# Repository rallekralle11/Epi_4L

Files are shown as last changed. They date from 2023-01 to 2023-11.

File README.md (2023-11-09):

# Epi
# This thing is about to get launched on Crowd Supply

Named after the Epipactis genus of orchids. The flower of one appears on the board.

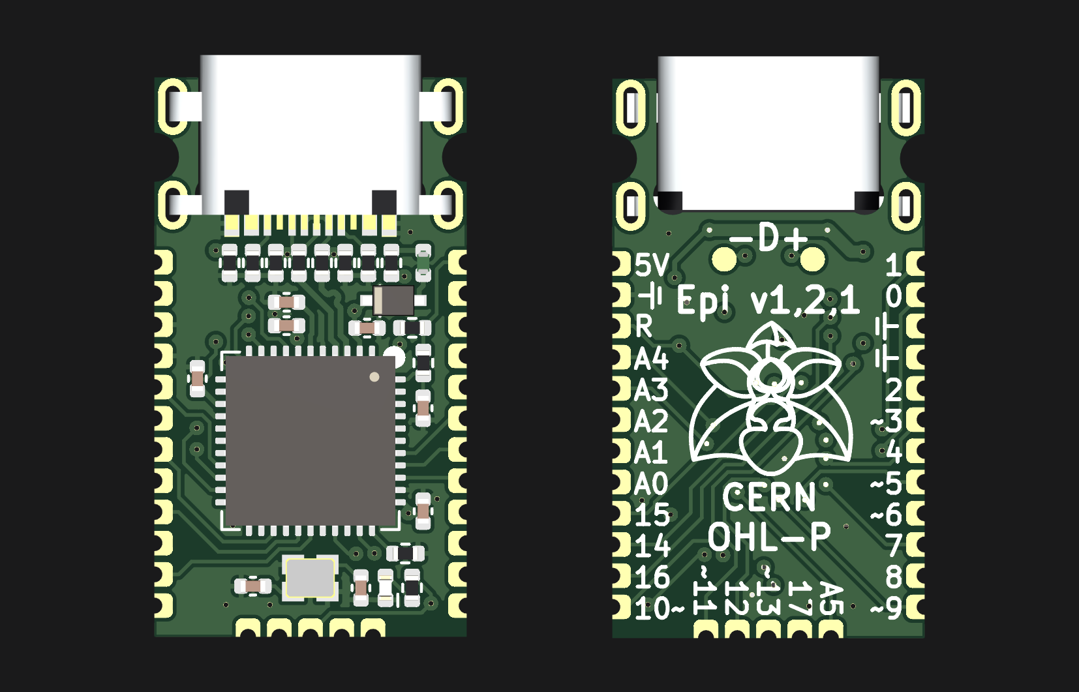
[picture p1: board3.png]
board


Data sheet: https://ping-el.se/wp-content/uploads/2023/10/datasheet.pdf
Kicad footprints: https://github.com/rallekralle11/kicad-lib

With such "amazing" features as:

USB power and data line ESD protection as well as power filtration and a fuse.

Crenellated pins.

No integrated voltage converter, only runs at 4,5-5,5v(down to 2,7 if you make it with an 8mhz crystal, or use the internal oscillator).

USB-C connector sunk into the board, and slighly portruding from the end for panel mounting.

1,27mm pin spacing.

Extra pins broken out.

Holes where M2 bolts can be used to hold it in place.

No rx/tx/power LEDs. Only one on pin 13 for testing.

Includes some custom footprints with 3D models.

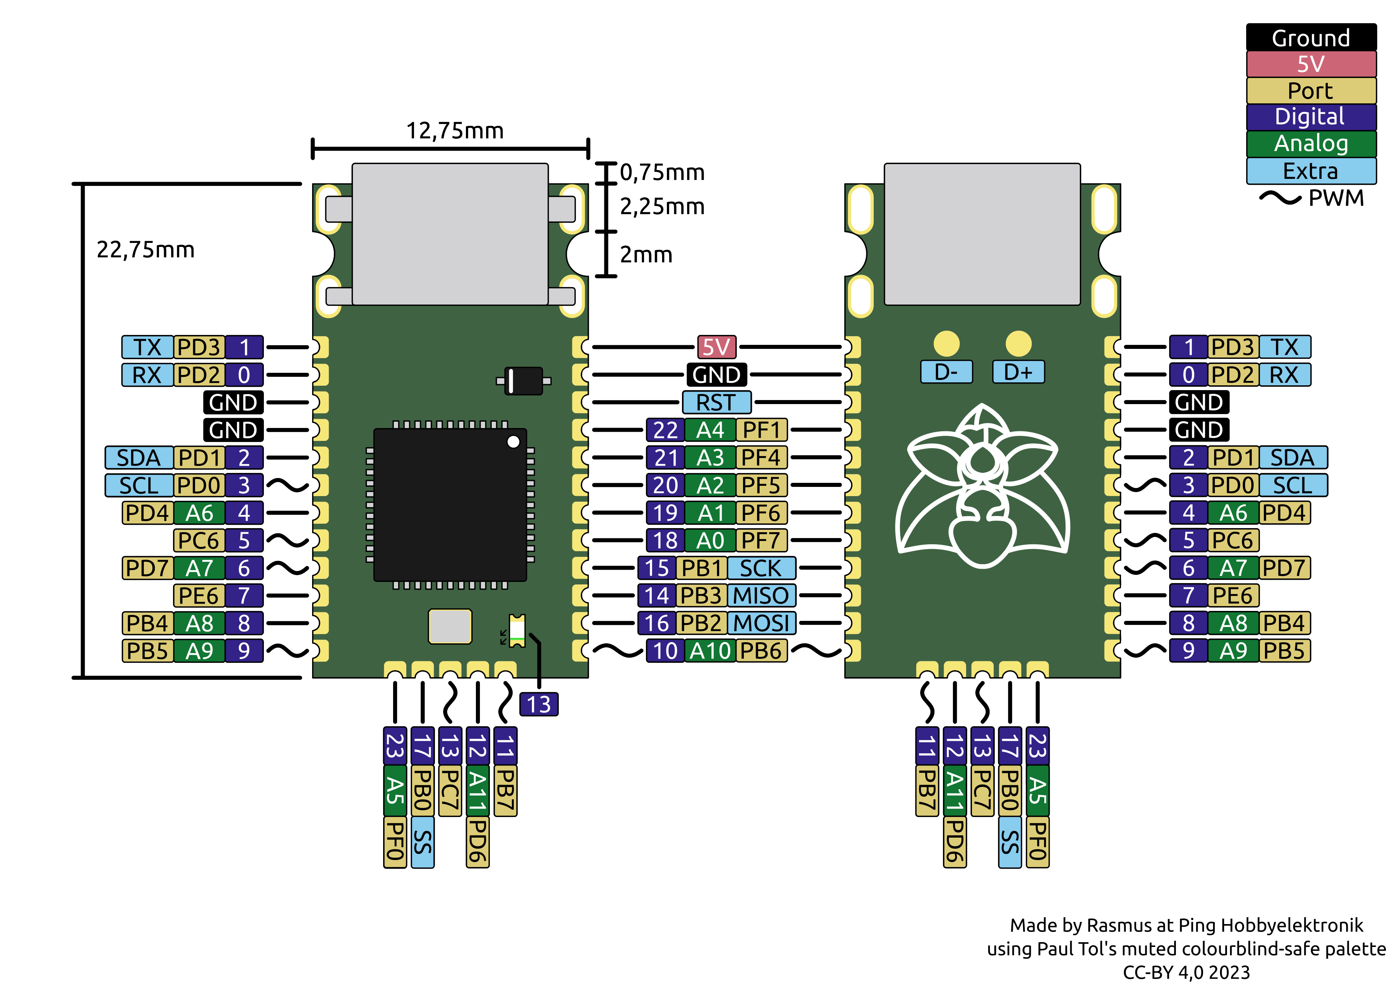
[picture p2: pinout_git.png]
pinout


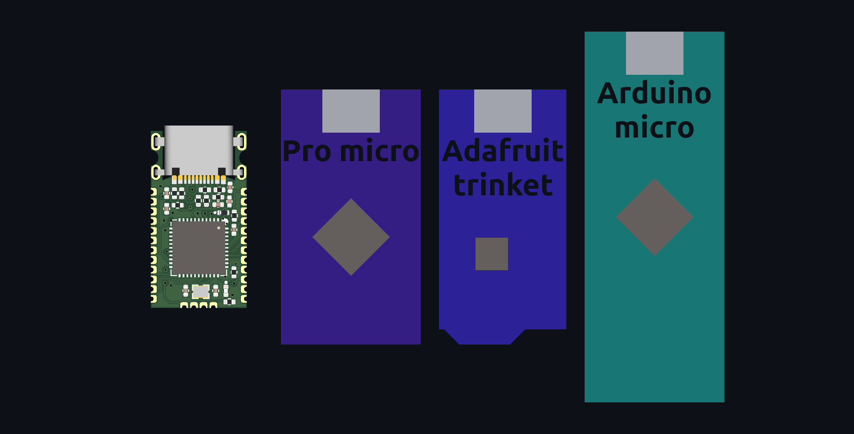
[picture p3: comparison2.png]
comp

Size comparisons.

Licensed under CERN-OHL-P v2

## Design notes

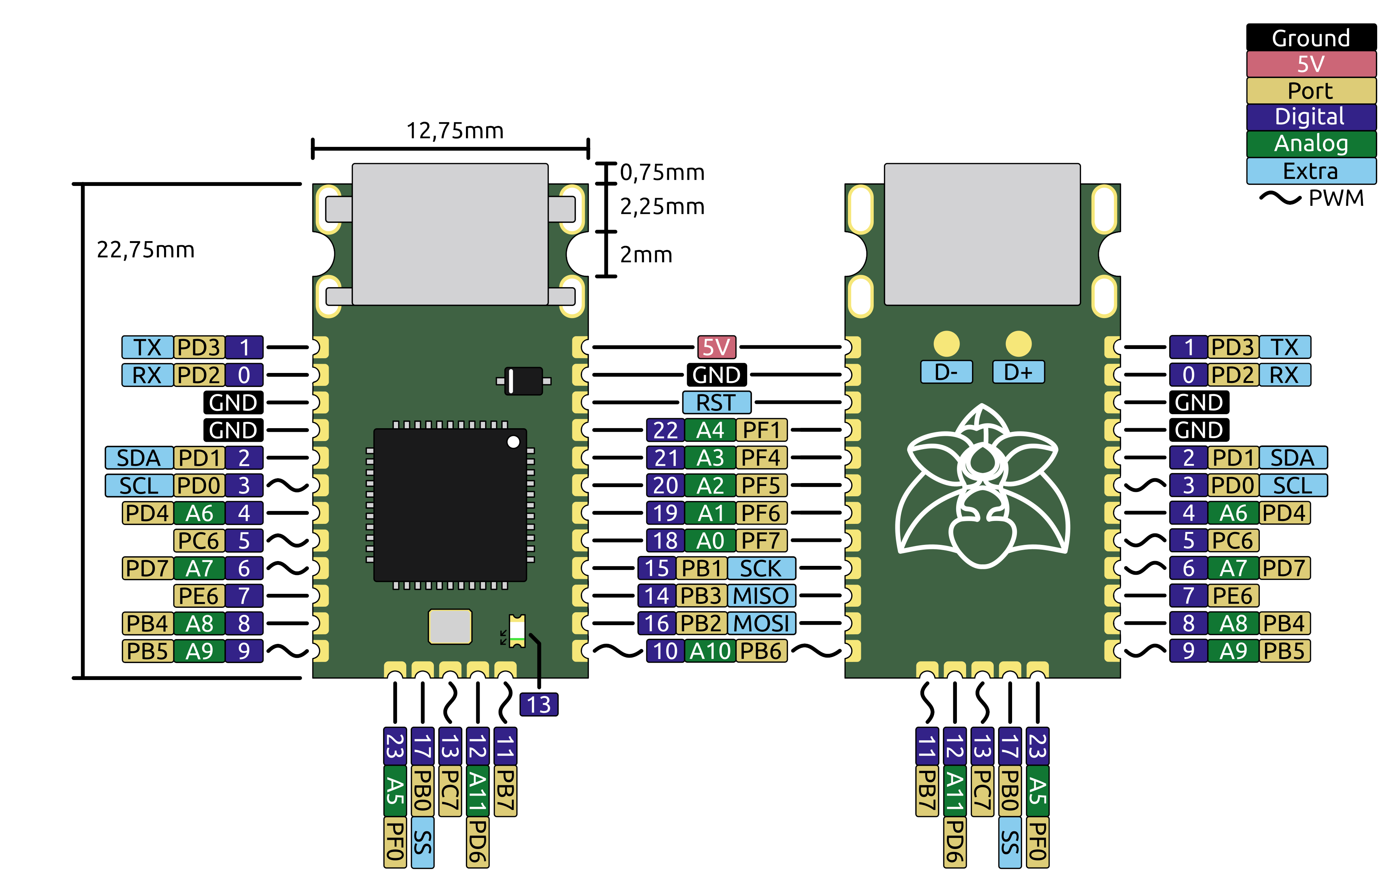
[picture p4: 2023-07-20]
epi-32u4-pinout-vit-crop.png

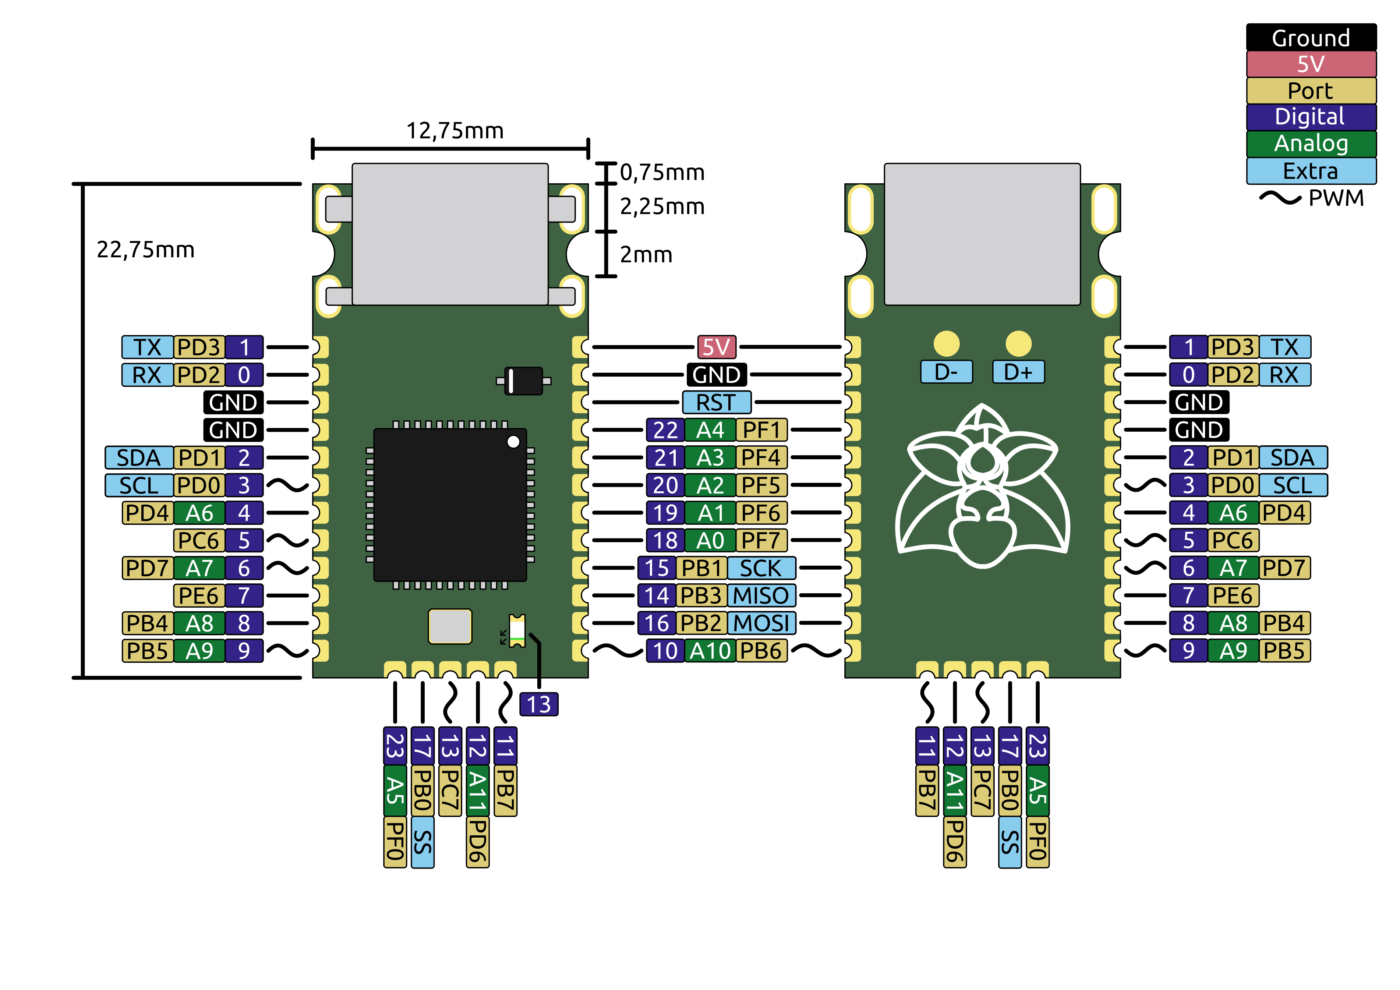
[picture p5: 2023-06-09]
epi-32u4-pinout-trans.png

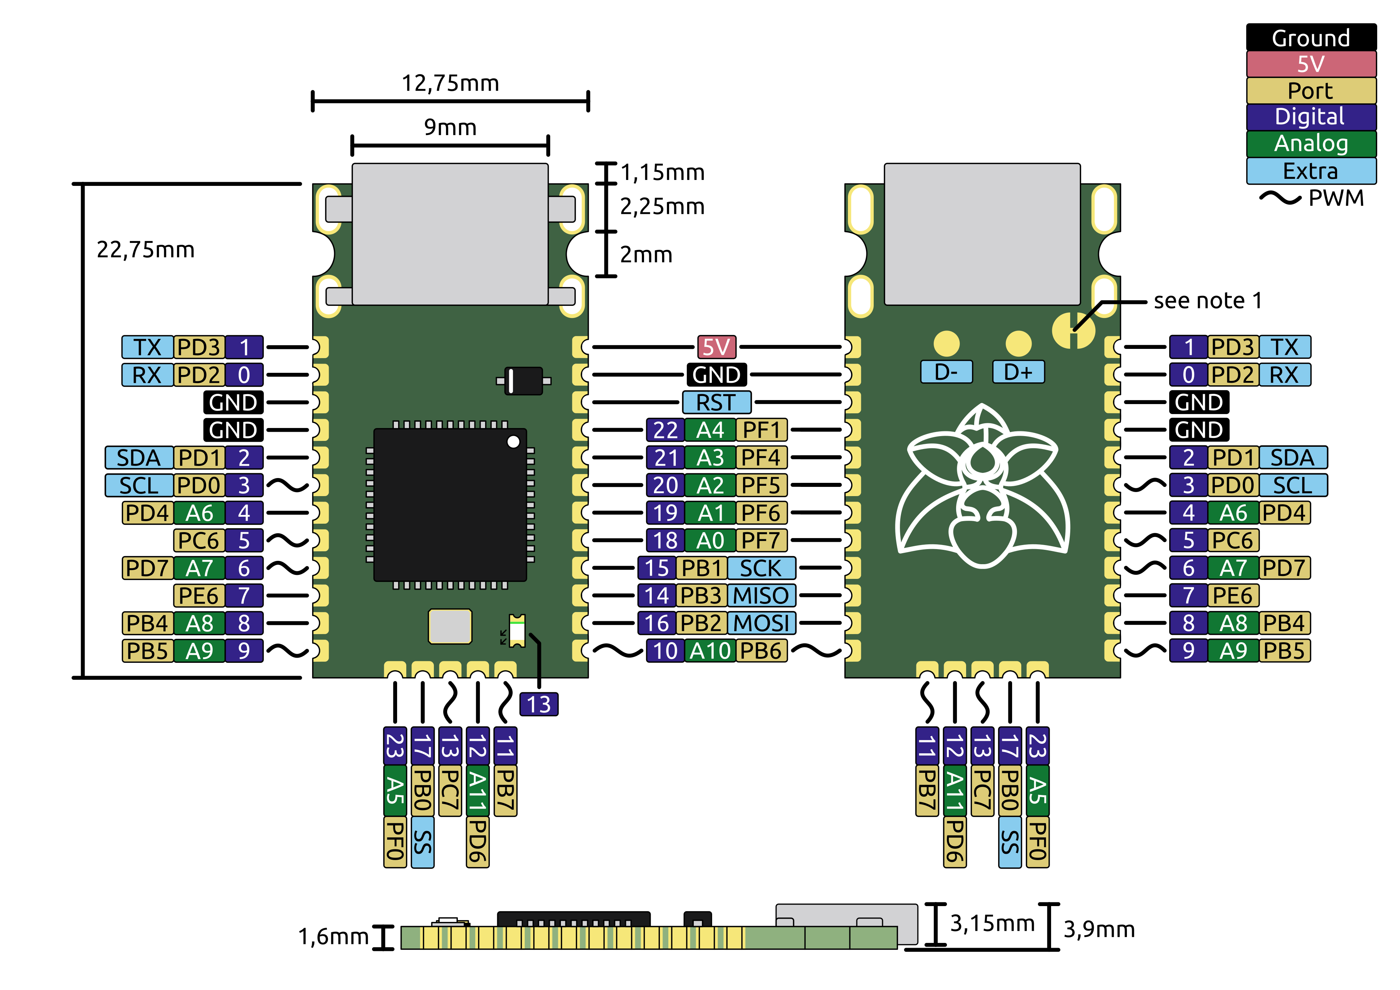
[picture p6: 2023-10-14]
pinout_trans.png

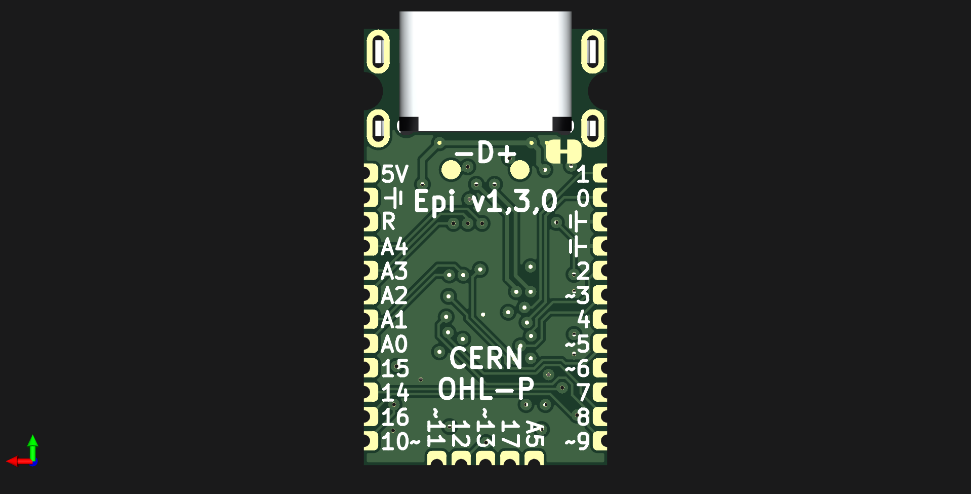
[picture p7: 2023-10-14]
B.png

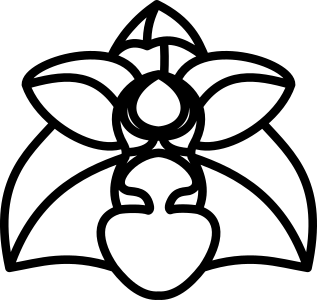
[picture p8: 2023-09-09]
extra/path1472-0-3-0-6.png

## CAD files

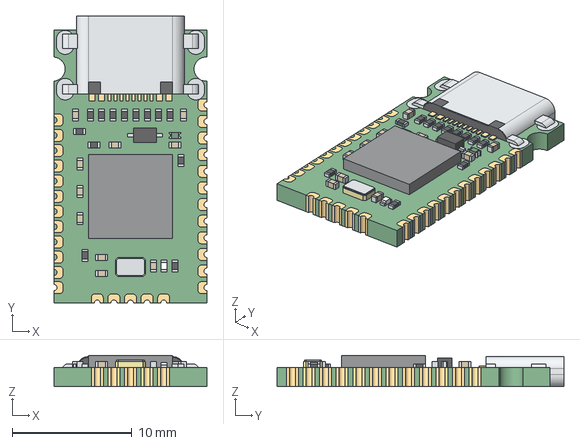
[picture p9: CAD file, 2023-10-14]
extra/Epi_footprint.stp
12.8 x 23.9 x 2.60 mm

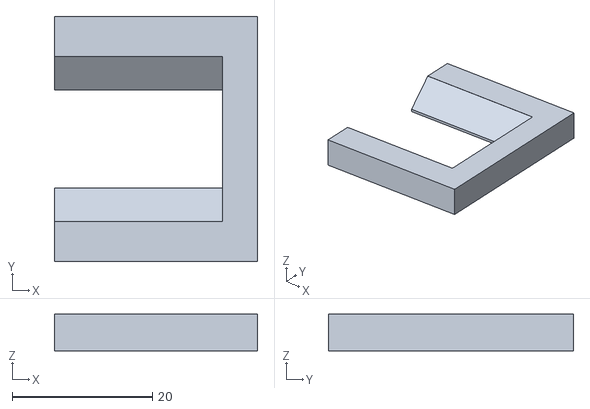
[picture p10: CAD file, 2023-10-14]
extra/jig.stl
29.0 x 35.0 x 5.25

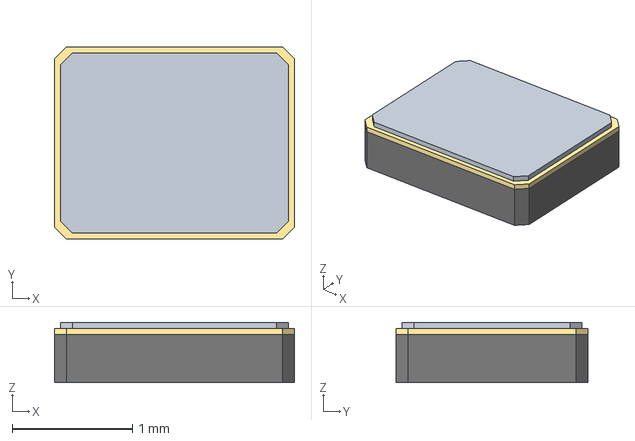
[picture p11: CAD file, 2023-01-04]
extra/crystal.stp
2.00 x 1.60 x 0.5 mm

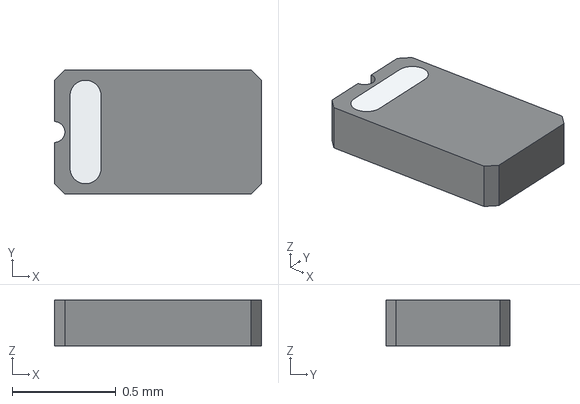
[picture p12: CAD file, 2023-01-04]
extra/diode.stp
1.00 x 0.6 x 0.22 mm

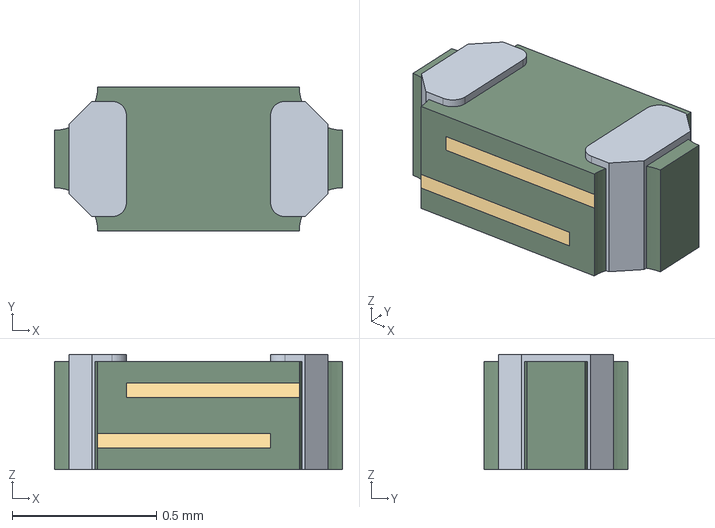
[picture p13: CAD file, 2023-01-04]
extra/1005_polyfuse.stp
1.00 x 0.5 x 0.4 mm

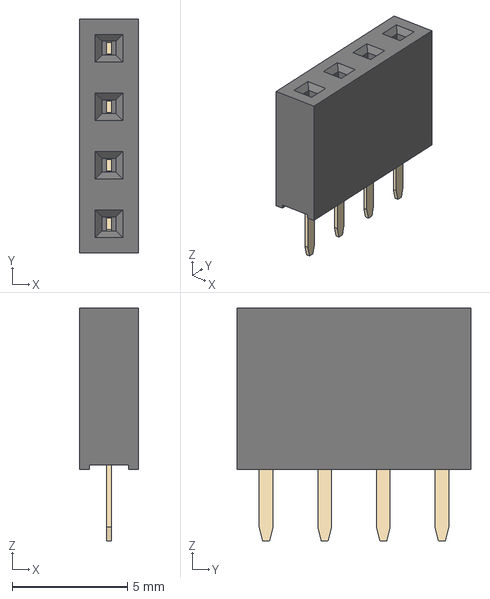
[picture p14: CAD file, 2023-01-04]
extra/PinSocket_1x04_P2.54mm_Vertical.step
2.54 x 10.2 x 10.1 mm

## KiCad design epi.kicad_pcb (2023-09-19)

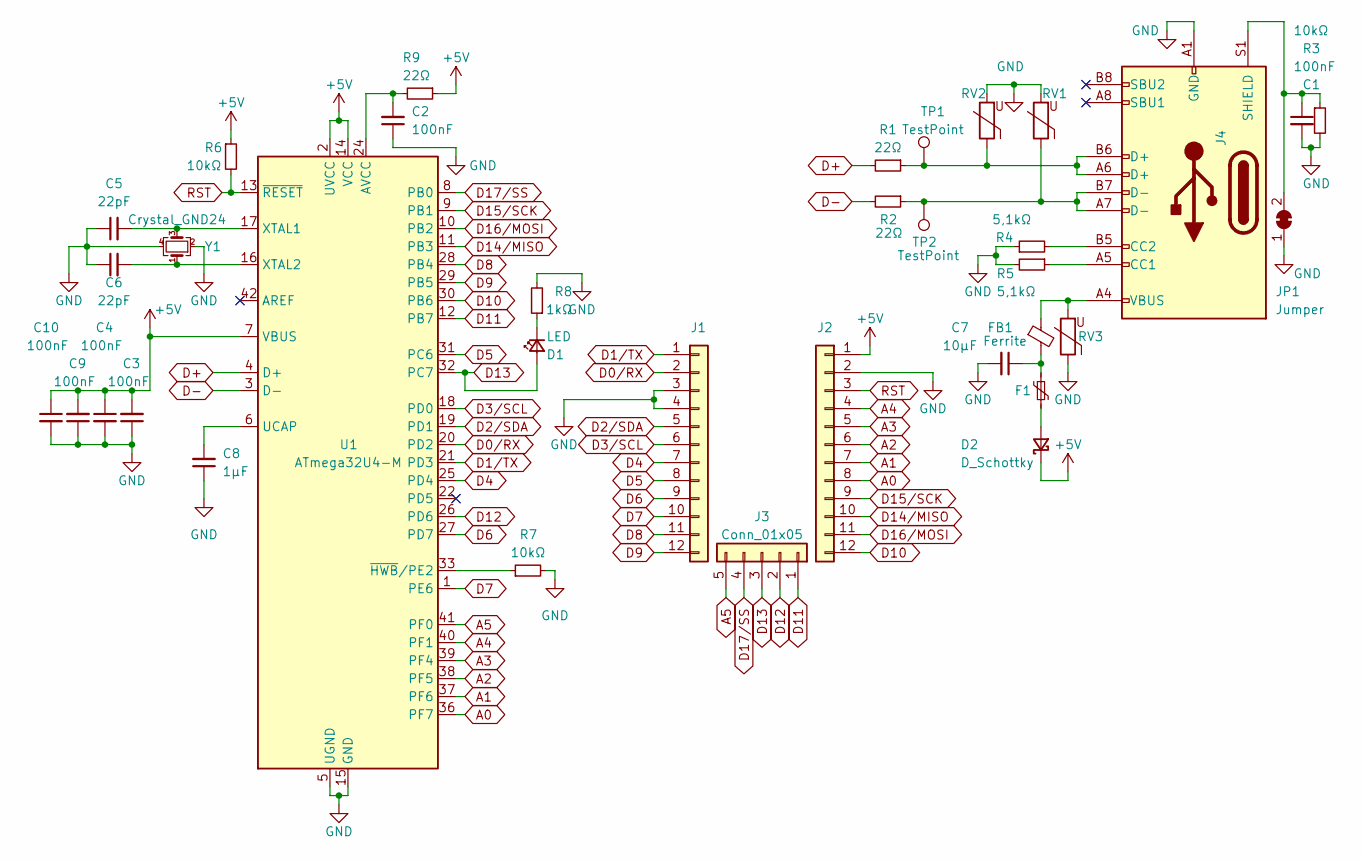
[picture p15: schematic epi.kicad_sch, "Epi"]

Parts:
C1, C2, C3, C4, C9, C10: 100nF; R_0402_1005Metric
C5, C6: 22pF; R_0402_1005Metric
C7: 10µF; R_0402_1005Metric
C8: 1µF; R_0402_1005Metric
D1: LED; LED_0402_1005Metric
D2: D_Schottky; SOD323_bättre
F1: Polyfuse 500mA HC; R_0402_1005Metric
FB1: Ferrite; R_0402_1005Metric
J1, J2: Connector 1x12; PinHeader_1x12_P1.27mm_Vertical
J3: Conn_01x05; PinHeader_1x05_P1.27mm_Vertical
J4: USB-C 2.0 mid-mount female connector; USB-C MC-314C-4P16
JP1: Jumper; SolderJumper-2_P1.3mm_Bridged_RoundedPad1.0x1.5mm
R1, R2, R9: 22Ω; R_0402_1005Metric
R3, R6, R7: 10kΩ; R_0402_1005Metric
R4, R5: 5,1kΩ; R_0402_1005Metric
R8: 1kΩ; R_0402_1005Metric
RV1, RV2, RV3: ESD protection varistor; R_0402_1005Metric
TP1, TP2: TestPoint; TestPoint_Pad_D1.0mm
U1: ATmega32U4-M; QFN-44-1EP_7x7mm_P0.5mm_EP5.2x5.2mm
Y1: Crystal_GND24; Crystal_SMD_2016-4Pin_2.0x1.6mm

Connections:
+5V: C3.2, C4.1, C9.2, C10.1, D2.1 (K), J2.1, R6.1, R9.1, U1.2 (UVCC), U1.7 (VBUS), U1.14 (VCC), U1.34 (VCC)
A0: J2.8, U1.36 (PF7)
A1: J2.7, U1.37 (PF6)
A2: J2.6, U1.38 (PF5)
A3: J2.5, U1.39 (PF4)
A4: J2.4, U1.40 (PF1)
A5: J3.5, U1.41 (PF0)
D0/RX: J1.2, U1.20 (PD2)
D1/TX: J1.1, U1.21 (PD3)
D2/SDA: J1.5, U1.19 (PD1)
D3/SCL: J1.6, U1.18 (PD0)
D4: J1.7, U1.25 (PD4)
D5: J1.8, U1.31 (PC6)
D6: J1.9, U1.27 (PD7)
D7: J1.10, U1.1 (PE6)
D8: J1.11, U1.28 (PB4)
D9: J1.12, U1.29 (PB5)
D10: J2.12, U1.30 (PB6)
D11: J3.1, U1.12 (PB7)
D12: J3.2, U1.26 (PD6)
D13: D1.2 (A), J3.3, U1.32 (PC7)
D14/MISO: J2.10, U1.11 (PB3)
D15/SCK: J2.9, U1.9 (PB1)
D16/MOSI: J2.11, U1.10 (PB2)
D17/SS: J3.4, U1.8 (PB0)
D+: R1.2, U1.4 (D+)
D-: R2.2, U1.3 (D-)
GND: C1.2, C2.1, C3.1, C4.2, C5.1, C6.1, C7.2, C8.1, C9.1, C10.2, J1.3, J1.4, J2.2, J4.A1 (GND), J4.A12 (GND), J4.B1 (GND), J4.B12 (GND), JP1.1 (A), R3.2, R4.1, R5.2, R7.2, R8.2, RV1.2, RV2.2, RV3.1, U1.5 (UGND), U1.15 (GND), U1.23 (GND), U1.35 (GND), U1.43 (GND), U1.45 (GND), Y1.2, Y1.4
unnamed: C2.2, R9.2, U1.24 (AVCC), U1.44 (AVCC)
unnamed: C7.1, F1.1, FB1.2
unnamed: D1.1 (K), R8.1
unnamed: D2.2 (A), F1.2
unnamed: FB1.1, J4.A4 (VBUS), J4.A9 (VBUS), J4.B4 (VBUS), J4.B9 (VBUS), RV3.2
unnamed: J4.A5 (CC1), R5.1
unnamed: J4.B5 (CC2), R4.2
unnamed: J4.A6 (D+), J4.B6 (D+), R1.1, RV2.1, TP1.1
unnamed: J4.A7 (D-), J4.B7 (D-), R2.1, RV1.1, TP2.1
unnamed: C1.1, J4.S1 (SHIELD), JP1.2 (B), R3.1
unnamed: C8.2, U1.6 (UCAP)
unnamed: C5.2, U1.17 (XTAL1), Y1.3
unnamed: C6.2, U1.16 (XTAL2), Y1.1
unnamed: R7.1, U1.33 (~HWB/PE2)
RST: J2.3, R6.2, U1.13 (~RESET)

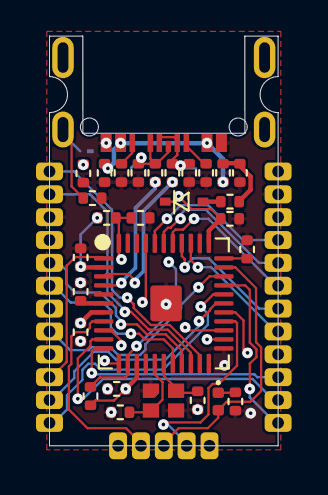
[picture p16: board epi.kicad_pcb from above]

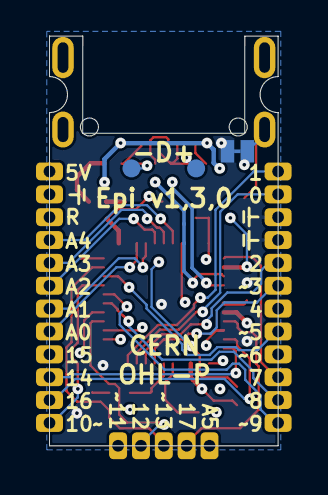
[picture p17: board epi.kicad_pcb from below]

Board: 4 copper layers, 12.7 x 22.8 mm, 37 parts (3 on the bottom side), 43 nets.

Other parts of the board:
DRILL1, DRILL2: NPTH

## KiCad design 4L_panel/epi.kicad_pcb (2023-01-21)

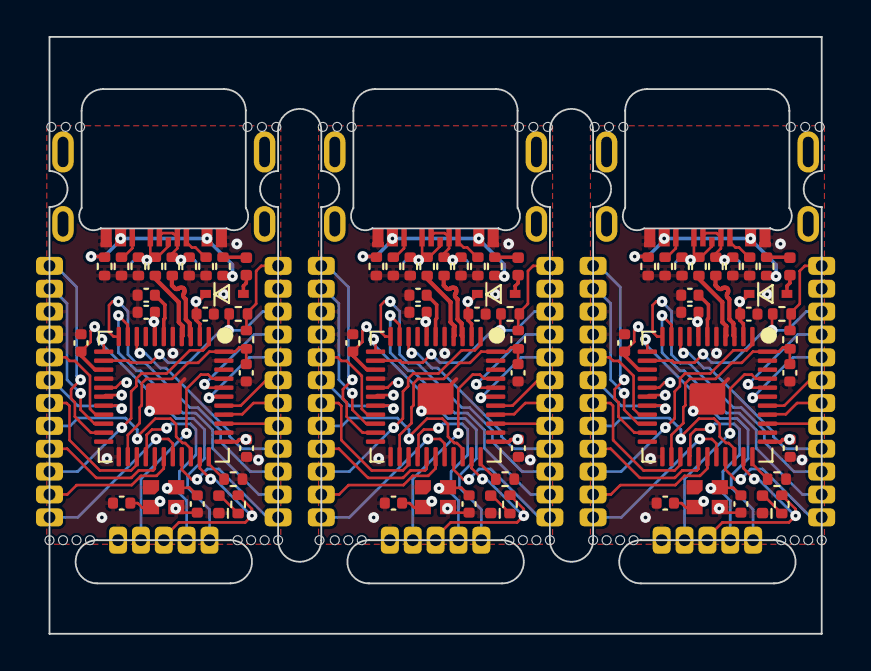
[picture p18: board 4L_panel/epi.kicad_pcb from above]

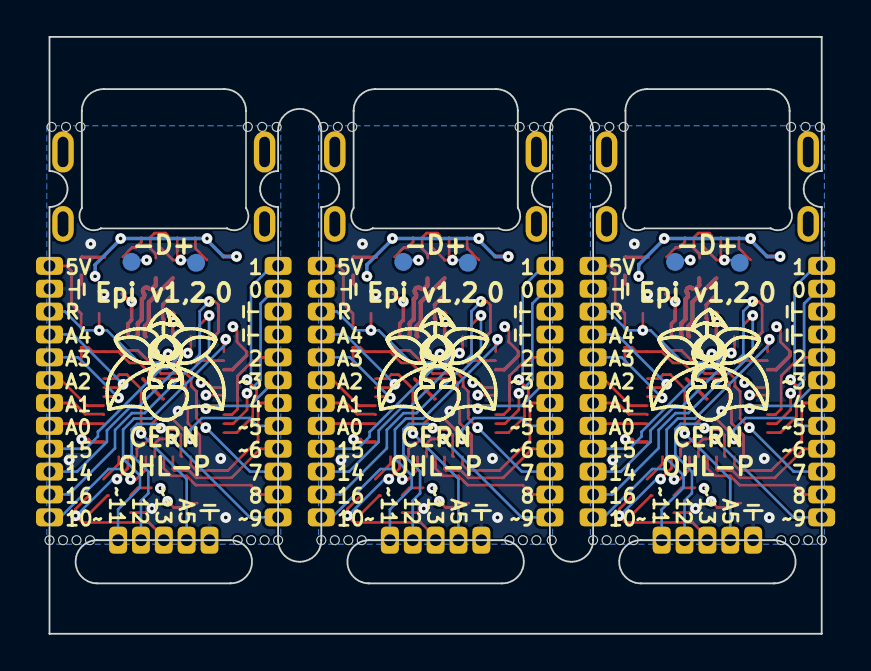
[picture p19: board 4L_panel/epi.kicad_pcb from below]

Board: 4 copper layers, 42.9 x 33.2 mm, 93 parts (6 on the bottom side), 41 nets.

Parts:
C2, C3, C4, C7, C9, C10, C11, C12, C16, C17, C18, C19, C20, C24, C25: 100nF; C_0402_1005Metric
C5, C6, C13, C14, C21, C22: 22pF; C_0402_1005Metric
C8, C15, C23: 1µF; C_0402_1005Metric
D1, D3, D5: LED; LED_0402_1005Metric
D2, D4, D6: D_Schottky; SOD323_bättre
F1, F2, F3: Polyfuse 500mA HC; Fuse_0402_1005Metric
FB1, FB2, FB3: Ferrite; R_0402_1005Metric
J1, J2, J5, J6, J9, J10: Connector 1x12; PinHeader_1x12_P1.27mm_Vertical
J3, J7, J11: Conn_01x05; PinHeader_1x05_P1.27mm_Vertical
J4, J8, J12: USB-C 2.0 mid-mount female connector; USB-C MC-314C-4P16
R1, R2, R3, R9, R10, R16, R17, R18, R24: 22Ω; R_0402_1005Metric
R4, R5, R11, R12, R19, R20: 5,1kΩ; R_0402_1005Metric
R6, R7, R13, R14, R21, R22: 10kΩ; R_0402_1005Metric
R8, R15, R23: 1kΩ; R_0402_1005Metric
RV1, RV2, RV3, RV4, RV5, RV6, RV7, RV8, RV9: ESD protection varistor; R_0402_1005Metric
TP1, TP2, TP3, TP4, TP5, TP6: TestPoint; TestPoint_Pad_D1.0mm
U1, U2, U3: ATmega32U4-M; QFN-44-1EP_7x7mm_P0.5mm_EP5.2x5.2mm
Y1, Y2, Y3: Crystal_GND24; Crystal_SMD_2016-4Pin_2.0x1.6mm

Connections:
+5V: C3.2, C4.1, C9.2, C10.1, C11.2, C12.1, C16.2, C17.1, C19.2, C20.1, C24.2, C25.1, D2.1 (K), D4.1 (K), D6.1 (K), J2.1, J6.1, J10.1, R6.1, R9.1, R13.1, R16.1, R21.1, R24.1, U1.2 (UVCC), U1.7 (VBUS), U1.14 (VCC), U1.34 (VCC), U2.2 (UVCC), U2.7 (VBUS), U2.14 (VCC), U2.34 (VCC), U3.2 (UVCC), U3.7 (VBUS), U3.14 (VCC), U3.34 (VCC)
A0: J2.8, J6.8, J10.8, U1.36 (PF7), U2.36 (PF7), U3.36 (PF7)
A1: J2.7, J6.7, J10.7, U1.37 (PF6), U2.37 (PF6), U3.37 (PF6)
A2: J2.6, J6.6, J10.6, U1.38 (PF5), U2.38 (PF5), U3.38 (PF5)
A3: J2.5, J6.5, J10.5, U1.39 (PF4), U2.39 (PF4), U3.39 (PF4)
A4: J2.4, J6.4, J10.4, U1.40 (PF1), U2.40 (PF1), U3.40 (PF1)
A5: J3.4, J7.4, J11.4, U1.41 (PF0), U2.41 (PF0), U3.41 (PF0)
D0/RX: J1.2, J5.2, J9.2, U1.20 (PD2), U2.20 (PD2), U3.20 (PD2)
D1/TX: J1.1, J5.1, J9.1, U1.21 (PD3), U2.21 (PD3), U3.21 (PD3)
D2/SDA: J1.5, J5.5, J9.5, U1.19 (PD1), U2.19 (PD1), U3.19 (PD1)
D3/SCL: J1.6, J5.6, J9.6, U1.18 (PD0), U2.18 (PD0), U3.18 (PD0)
D4: J1.7, J5.7, J9.7, U1.25 (PD4), U2.25 (PD4), U3.25 (PD4)
D5: J1.8, J5.8, J9.8, U1.31 (PC6), U2.31 (PC6), U3.31 (PC6)
D6: J1.9, J5.9, J9.9, U1.27 (PD7), U2.27 (PD7), U3.27 (PD7)
D7: J1.10, J5.10, J9.10, U1.1 (PE6), U2.1 (PE6), U3.1 (PE6)
D8: J1.11, J5.11, J9.11, U1.28 (PB4), U2.28 (PB4), U3.28 (PB4)
D9: J1.12, J5.12, J9.12, U1.29 (PB5), U2.29 (PB5), U3.29 (PB5)
D10: J2.12, J6.12, J10.12, U1.30 (PB6), U2.30 (PB6), U3.30 (PB6)
D11: J3.1, J7.1, J11.1, U1.12 (PB7), U2.12 (PB7), U3.12 (PB7)
D12: J3.2, J7.2, J11.2, U1.26 (PD6), U2.26 (PD6), U3.26 (PD6)
D13: J3.3, J7.3, J11.3, R8.1, R15.1, R23.1, U1.32 (PC7), U2.32 (PC7), U3.32 (PC7)
D14/MISO: J2.10, J6.10, J10.10, U1.11 (PB3), U2.11 (PB3), U3.11 (PB3)
D15/SCK: J2.9, J6.9, J10.9, U1.9 (PB1), U2.9 (PB1), U3.9 (PB1)
D16/MOSI: J2.11, J6.11, J10.11, U1.10 (PB2), U2.10 (PB2), U3.10 (PB2)
D+: R1.2, R3.2, R17.2, U1.4 (D+), U2.4 (D+), U3.4 (D+)
D-: R2.2, R10.2, R18.2, U1.3 (D-), U2.3 (D-), U3.3 (D-)
GND: C2.1, C3.1, C4.2, C5.1, C6.1, C7.1, C8.1, C9.1, C10.2, C11.1, C12.2, C13.1, C14.1, C15.1, C16.1, C17.2, C18.1, C19.1, C20.2, C21.1, C22.1, C23.1, C24.1, C25.2, D1.1 (K), D3.1 (K), D5.1 (K), J1.3, J1.4, J2.2, J3.5, J4.A1 (GND), J4.B12 (GND), J5.3, J5.4, J6.2, J7.5, J8.A1 (GND), J8.B12 (GND), J9.3, J9.4, J10.2, J11.5, J12.A1 (GND), J12.B12 (GND), R4.1, R5.2, R7.2, R11.1, R12.2, R14.2, R19.1, R20.2, R22.2, RV1.2, RV2.2, RV3.1, RV4.2, RV5.2, RV6.1, RV7.2, RV8.2, RV9.1, U1.5 (UGND), U1.15 (GND), U1.23 (GND), U1.35 (GND), U1.43 (GND), U1.45 (GND), U2.5 (UGND), U2.15 (GND), U2.23 (GND), U2.35 (GND), U2.43 (GND), U2.45 (GND), U3.5 (UGND), U3.15 (GND), U3.23 (GND), U3.35 (GND), U3.43 (GND), U3.45 (GND), Y1.2, Y1.4, Y2.2, Y2.4, Y3.2, Y3.4
unnamed: C2.2, C7.2, C18.2, R9.2, R16.2, R24.2, U1.24 (AVCC), U1.44 (AVCC), U2.24 (AVCC), U2.44 (AVCC), U3.24 (AVCC), U3.44 (AVCC)
unnamed: C5.2, C13.2, C21.2, U1.17 (XTAL1), U2.17 (XTAL1), U3.17 (XTAL1), Y1.3, Y2.3, Y3.3
unnamed: C6.2, C14.2, C22.2, U1.16 (XTAL2), U2.16 (XTAL2), U3.16 (XTAL2), Y1.1, Y2.1, Y3.1
unnamed: C8.2, C15.2, C23.2, U1.6 (UCAP), U2.6 (UCAP), U3.6 (UCAP)
unnamed: D1.2 (A), D3.2 (A), D5.2 (A), R8.2, R15.2, R23.2
unnamed: D2.2 (A), D4.2 (A), D6.2 (A), F1.2, F2.2, F3.2
unnamed: F1.1, F2.1, F3.1, FB1.2, FB2.2, FB3.2
unnamed: FB1.1, FB2.1, FB3.1, J4.A4 (VBUS), J4.A9 (VBUS), J8.A4 (VBUS), J8.A9 (VBUS), J12.A4 (VBUS), J12.A9 (VBUS), RV3.2, RV6.2, RV9.2
unnamed: J4.A5 (CC1), J8.A5 (CC1), J12.A5 (CC1), R5.1, R12.1, R20.1
unnamed: J4.A6 (D+), J4.B6 (D+), J8.A6 (D+), J8.B6 (D+), J12.A6 (D+), J12.B6 (D+), R1.1, R3.1, R17.1, RV2.1, RV5.1, RV8.1, TP1.1, TP3.1, TP5.1
unnamed: J4.A7 (D-), J4.B7 (D-), J8.A7 (D-), J8.B7 (D-), J12.A7 (D-), J12.B7 (D-), R2.1, R10.1, R18.1, RV1.1, RV4.1, RV7.1, TP2.1, TP4.1, TP6.1
unnamed: J4.B5 (CC2), J8.B5 (CC2), J12.B5 (CC2), R4.2, R11.2, R19.2
unnamed: R7.1, R14.1, R22.1, U1.33 (~HWB/PE2), U2.33 (~HWB/PE2), U3.33 (~HWB/PE2)
RST: J2.3, J6.3, J10.3, R6.2, R13.2, R21.2, U1.13 (~RESET), U2.13 (~RESET), U3.13 (~RESET)

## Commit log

2023-01-07 minor changes
    [epi.kicad_pcb]
2023-01-21 minor design changes and pinout diagram added
    [epi.kicad_pcb, epi.kicad_sch]
2023-01-22 removed broken files
    [epi.step]
2023-02-04 added gerbers
2023-06-08 new computer, new updates
    [epi.kicad_pcb, epi.kicad_sch]
2023-06-08 gerbers update
    [epi.kicad_pcb]
2023-06-09 gerbers and pictures
    [epi.kicad_pcb]
2023-07-20 slight edge cuts change
    [epi.kicad_pcb]
2023-07-20 messing with outline and also spark gap
    [epi.kicad_pcb, epi.kicad_sch]
2023-07-22 changed the method for inset corners to make space for the USB port
    [epi.kicad_pcb]
2023-07-23 USB shield connection set up
    [epi.kicad_pcb, epi.kicad_sch]
2023-07-23 guess it needs a new BOM as well
2023-09-09 big redesign
    [epi.dsn, epi.kicad_pcb, epi.kicad_sch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]
2023-09-19 little fix and updated gerbers
    [epi-B_Cu.gbr, epi-B_Mask.gbr, epi-B_Paste.gbr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]
2023-10-14 bit of everything
    [Epi_footprint.stp, jig.stl]

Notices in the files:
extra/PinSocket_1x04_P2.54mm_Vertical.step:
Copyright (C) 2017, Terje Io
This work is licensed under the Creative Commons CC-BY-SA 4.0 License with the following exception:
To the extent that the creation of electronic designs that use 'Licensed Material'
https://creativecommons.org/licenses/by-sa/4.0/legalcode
